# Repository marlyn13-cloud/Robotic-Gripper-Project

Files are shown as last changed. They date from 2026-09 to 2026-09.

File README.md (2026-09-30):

# Robotic-Gripper-Project

**Course:** CSIT431/CSIT531 — Introduction to Robotics

---

## Overview

Build a **Python GUI** (CustomTkinter) that controls a **3D-printed gripper** via an **Arduino Mega2560** over USB serial. A webcam feed uses **MediaPipe** to detect hand gestures, which open/close the gripper's **9g servo** in real time. The gripper must pick up **20 objects** of different shapes in a timed competition.

---

### Task
Use hand gesture recognition to control the gripper to **grasp objects from one box** and **deliver them to another box 30 cm away**.

### Rules
1. **20 objects** with different shapes, each labeled with a score
2. Distance between boxes: **30 cm**
3. **3 trials per object** — first-try success loses remaining trials for that object
4. Gripper must be controlled by **hand gesture recognition only**
5. **10 seconds per trial** — stop and start next trial if time runs out
6. Object falls INTO target box from gripper during delivery = **no points**
7. Object falls OUTSIDE target box = **get points but -1 deduction**
8. Gripper loses control = **-2 points per loss (max -8 deducted)**
9. Judges record scores on a performance sheet

---

## Part 1: 3D Design

### Selected Design
- **RobotGeek 9G Servo Gripper** — [Thingiverse thing:2083312](https://www.thingiverse.com/thing:2083312)
- Modify using **Tinkercad**, **Fusion 360**, or **Python (trimesh)**

### Design Requirements
| Parameter | Value |
|---|---|
| Hole size | 2.8 mm |
| Screw length compatibility | 18–24 mm |
| Servo attachment screws | No changes needed (keep as-is) |

### Bill of Materials (33 parts to print)

| # | Part | Qty | Notes |
|---|---|---|---|
| 1 | `BottomPlate.stl` | 1 | Base frame plate |
| 2 | `TopPlate.stl` | 1 | Top frame plate |
| 3 | `BackPlate.stl` | 1 | Rear structural support |
| 4 | `BackPlateSpacer.stl` | 1 | Rear spacer |
| 5 | `Gear.stl` | 1 | Central gear (servo-driven, hidden between plates) |
| 6 | `LeftFinger.stl` | **2** | Left gripper arms (stacked, has integrated gear teeth) |
| 7 | `RightFinger.stl` | **2** | Right gripper arms (stacked, has integrated gear teeth) |
| 8 | `FingerTip.stl` | **2** | Grip contact tips |
| 9 | `FingerTip-Plate.stl` | **4** | Tip mounting plates |
| 10 | `9GSpacer.stl` | 1 | Servo mount spacer |
| 11 | `9GSpacer-3mm.stl` | 1 | 3mm servo spacer variant |
| 12 | `3mmSpacer.stl` | **8** | General spacers (between plates) |
| 13 | `15mmStandoff.stl` | **8** | Standoffs (plate separation) |
| — | `Fitec-9g.stl` | — | Reference only — do NOT print |
| — | `GripperASM.stl` | — | Assembly reference — do NOT print |

### Hole Modifications (done via Python/trimesh)
- 7 parts modified: BottomPlate, TopPlate, LeftFinger, RightFinger, FingerTip-Plate, 3mmSpacer, 15mmStandoff
- All ~3.0 mm screw holes → **2.8 mm**
- Servo mount holes (2.0 mm) left unchanged

---

## Part 2: Hardware Setup

### System Diagram
```
  ┌──────────┐    USB     ┌──────────────┐   3 wires   ┌──────────┐
  │ COMPUTER │ ─────────> │   ARDUINO    │ ──────────> │ GRIPPER  │
  │ (Python  │   Serial   │  MEGA 2560   │  Red=5V     │ (9g Servo│
  │  GUI)    │            │              │  Brown=GND  │  inside) │
  └──────────┘            └──────────────┘  Yellow=A2  └──────────┘
       │
     Webcam
   (MediaPipe)
```

### Board
- **Arduino Mega2560** (provided by instructor)

### Servo Wiring
| Wire Color | Connect To |
|---|---|
| Red | 5V |
| Dark/Brown | Ground |
| Yellow/Signal | Pin **A2** (default in provided Arduino code) |

### Arduino Code
- Provided via Canvas — **no changes needed**
- Upload using Arduino IDE
- Install **Servo library**: [arduino.cc/libraries/servo](https://www.arduino.cc/reference/en/libraries/servo/)
- Serial port:
  - **Windows:** `COMx`
  - **macOS:** `/dev/cu.usbmodemXXXX`
- Python code supports **auto port detection**

---

## Part 3: Python Development

### Environment
- **Python version:** 3.11 or 3.12 (64-bit) — compatible with MediaPipe (supports 3.9–3.12)
- **IDE:** VSCode with **Python Extension Pack** (optional but recommended)

### Dependencies (install via pip)
```
pip install pyserial customtkinter mediapipe opencv-contrib-python
```

| Package | Purpose |
|---|---|
| `pyserial` | Serial communication with Arduino Mega2560 |
| `customtkinter` | Modern Python GUI framework |
| `mediapipe` | Hand landmark / gesture detection |
| `opencv-contrib-python` | Camera input & image processing |

### Architecture
1. **GUI (CustomTkinter)** — Main window with camera feed, controls, and status
2. **Hand Tracking (MediaPipe + OpenCV)** — Detect hand landmarks from webcam
3. **Gesture Interpretation** — Map hand open/close to gripper open/close commands
4. **Serial Communication (pyserial)** — Send servo angle commands to Arduino over USB
5. **Auto Port Detection** — Automatically find the connected Arduino serial port

### Workflow
1. Connect Arduino Mega2560 via USB (servo already wired)
2. Run the Python GUI (`python xxx.py`)
3. Select Python 3.x interpreter in VSCode if needed
4. Serial port is auto-detected (or manually set in code)
5. Webcam opens → MediaPipe tracks hand → gestures control gripper

---

## Part 4: Test Objects (20 in competition)

Items in the project box — each labeled with a score. Must grasp from one box and deliver to another (30 cm apart).

| # | Object | Notes | Difficulty |
|---|---|---|---|
| 1 | 9g Servo motor (blue) | Small, rigid, rectangular | Easy |
| 2 | Yellow servo/motor component | Small, irregular shape | Easy |
| 3 | 3D printed robotic arm/hand | Gray, multi-part, medium size | Medium |
| 4 | Long screw/bolt | Thin, cylindrical | Hard |
| 5 | Plastic fork | Lightweight, flat handle | Medium |
| 6 | Green lid/cap | Round, flat | Medium |
| 7 | Red container/jar | Cylindrical, medium | Easy |
| 8 | Yellow wheel/gear piece | Round with spokes | Medium |
| 9 | 3D printed head | Gray, large, heaviest item | Hard |
| 10 | Orange craft knife | Thin, elongated | Medium |
| 11 | Blue donut/ring | Round, hollow center | Medium |
| 12 | Tube (glue or similar) | Cylindrical, small | Easy |
| 13 | Small connectors & wires | Various tiny parts | Hard |

*Competition will have 20 objects total — these are samples.*

---

## Resources

### Servo Control
- [Arduino Servo Library](https://www.arduino.cc/reference/en/libraries/servo/)
- [Servo Motor with Arduino](https://makersportal.com/blog/2020/3/14/arduino-servo-motor-control)
- [Python + Arduino Servo](https://github.com/jumejume1/python-arduino-basic/tree/main/servo-control)

### Arduino Reference
- [Arrays](https://www.arduino.cc/reference/en/language/variables/data-types/array/)
- [If Statement](https://www.arduino.cc/reference/en/language/structure/control-structure/if/)
- [For Loops](https://www.arduino.cc/reference/en/language/structure/control-structure/for/)
- [While Loops](https://www.arduino.cc/reference/en/language/structure/control-structure/while/)

### Other Gripper Designs for Reference
- [EEZYbotARM](https://www.thingiverse.com/thing:2195839)
- [Simple 9g Servo Gripper](https://www.thingiverse.com/thing:2302957)
- [Rack & Pinion Gripper](https://www.thingiverse.com/thing:2661755)
- [3-Finger Chess Robot Gripper](https://www.thingiverse.com/thing:1322867)
- [Parametric Robot Claw](https://www.thingiverse.com/thing:27468)
----------
Demo Video Link

https://drive.google.com/file/d/11LuLujdieBRYz85RrpzKWeHXCLVEo9Aj/view?usp=sharing

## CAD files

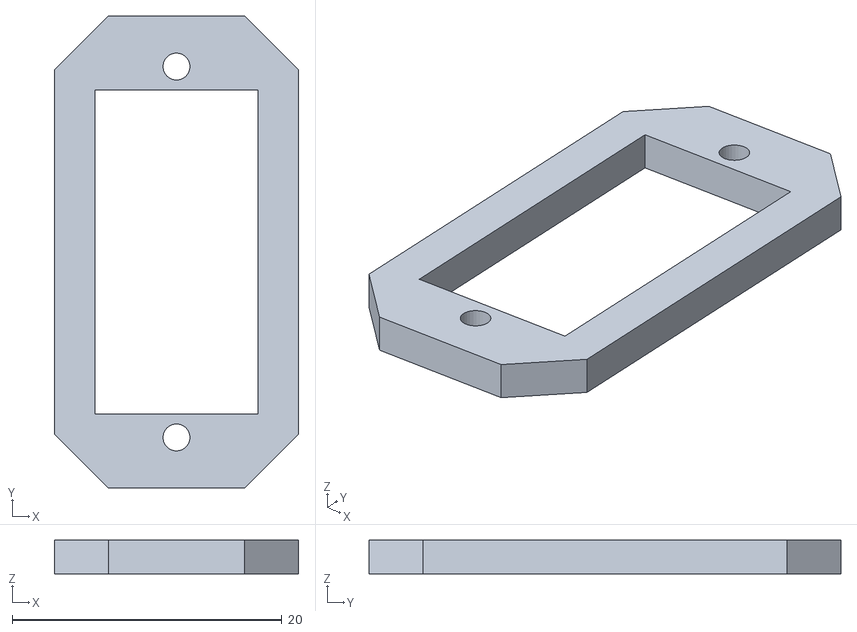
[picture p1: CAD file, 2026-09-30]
STL-Final/9GSpacer-3mm.stl
18.1 x 35.0 x 2.50

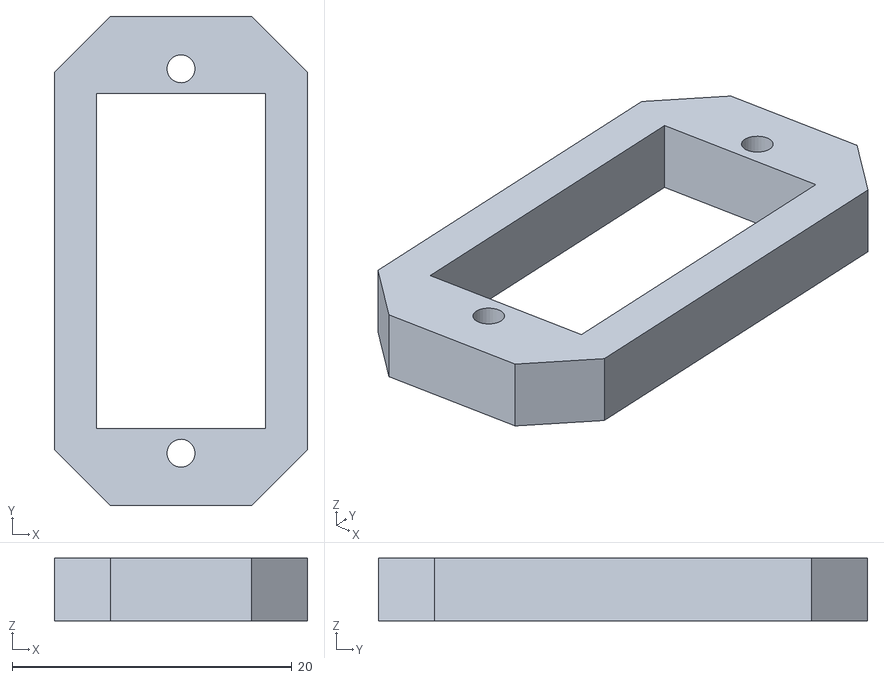
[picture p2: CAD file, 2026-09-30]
STL-Final/9GSpacer.stl
18.1 x 35.0 x 4.50

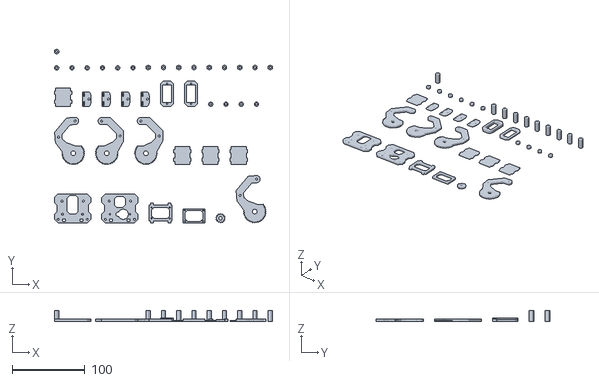
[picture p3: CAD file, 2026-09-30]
STL-Final/ALL_33_PARTS.stl
300.0 x 239.3 x 15.0

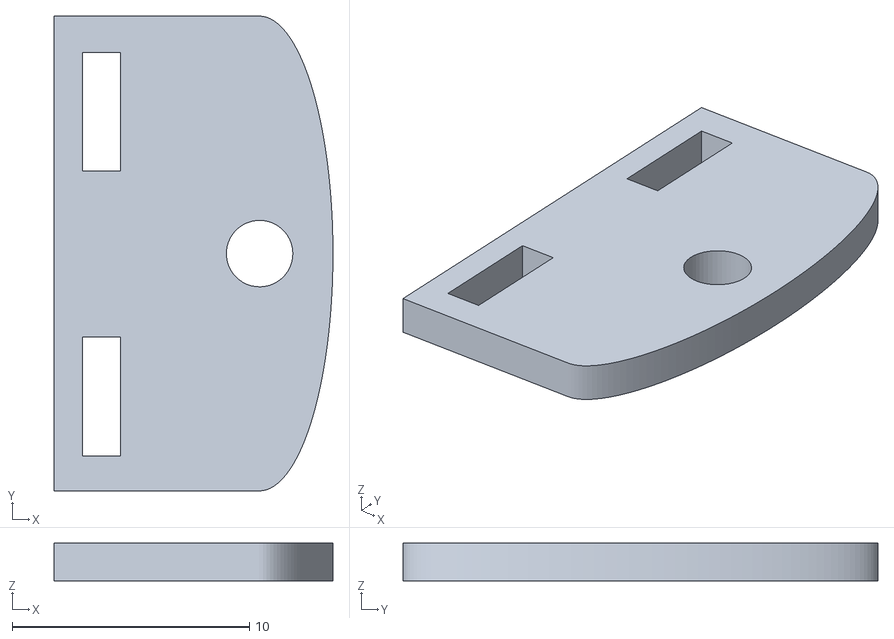
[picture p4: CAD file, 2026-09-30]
STL-Final/FingerTip-Plate.stl
11.8 x 20.0 x 1.60

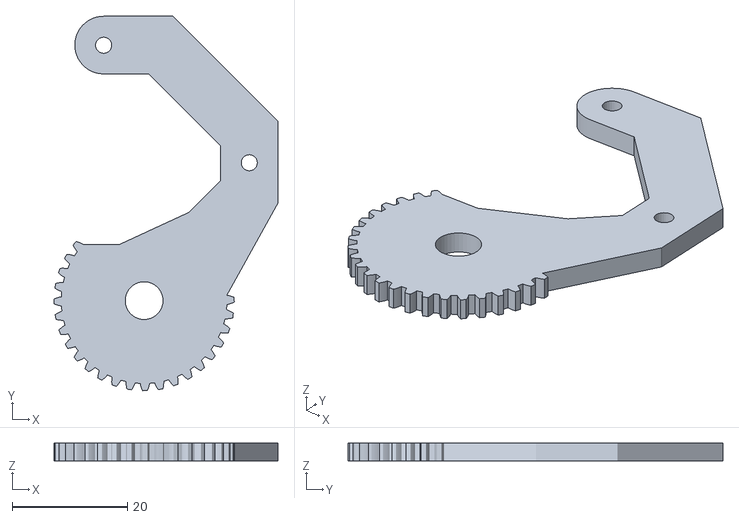
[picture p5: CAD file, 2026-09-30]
STL-Final/RightFinger.stl
38.8 x 64.9 x 3.10

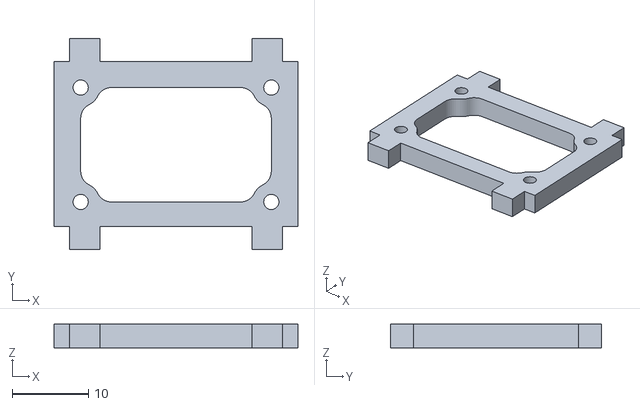
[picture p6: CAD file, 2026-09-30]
STL-Final/BackPlate.stl
32.0 x 27.7 x 3.10

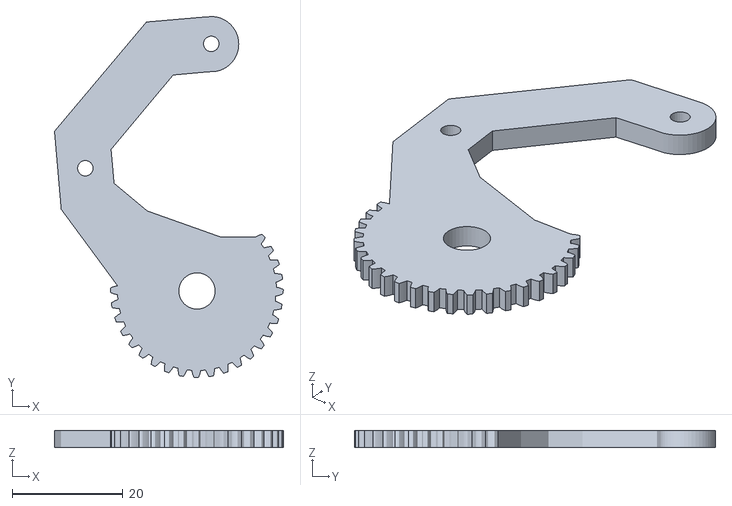
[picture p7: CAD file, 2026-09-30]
STL-Final/LeftFinger.stl
41.4 x 65.2 x 3.10

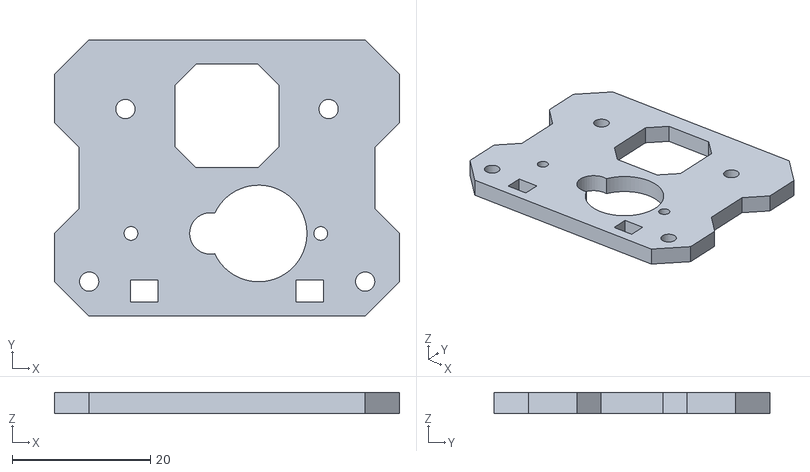
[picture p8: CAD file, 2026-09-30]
STL-Final/TopPlate.stl
50.0 x 40.0 x 3.10

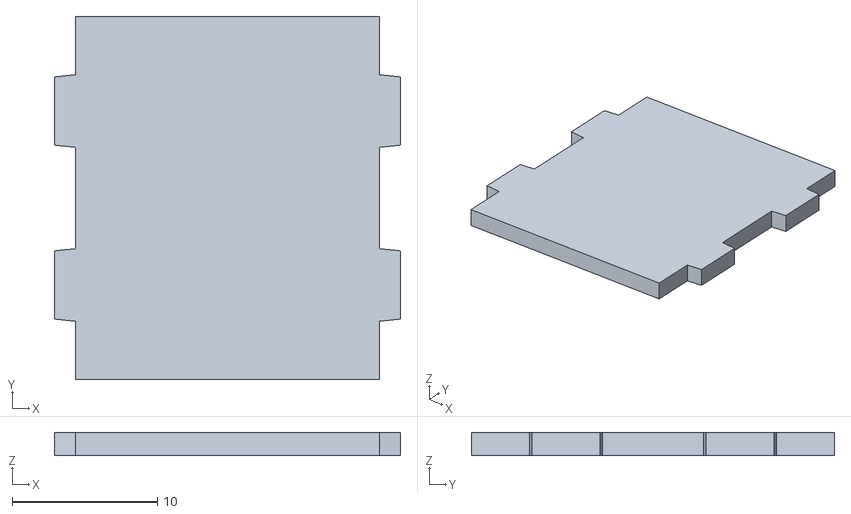
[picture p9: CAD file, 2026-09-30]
STL-Final/FingerTip.stl
23.8 x 25.0 x 1.60

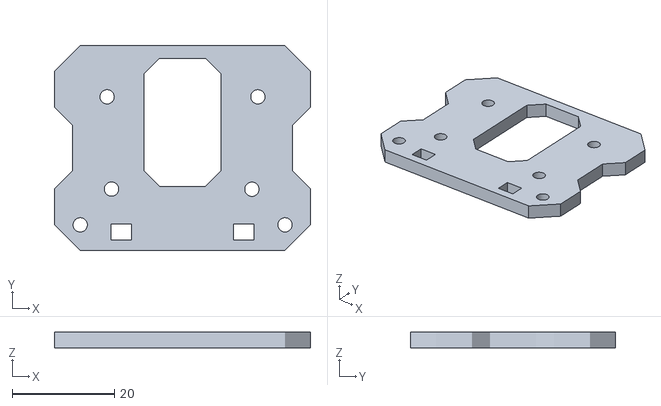
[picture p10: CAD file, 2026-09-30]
STL-Final/BottomPlate.stl
50.0 x 40.0 x 3.10

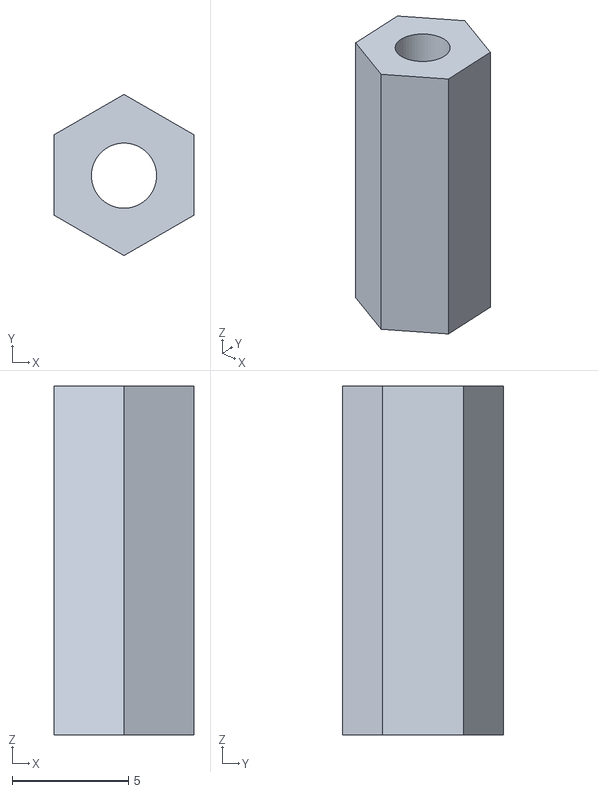
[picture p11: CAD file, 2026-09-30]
STL-Final/15mmStandoff.stl
6.00 x 6.93 x 15.0

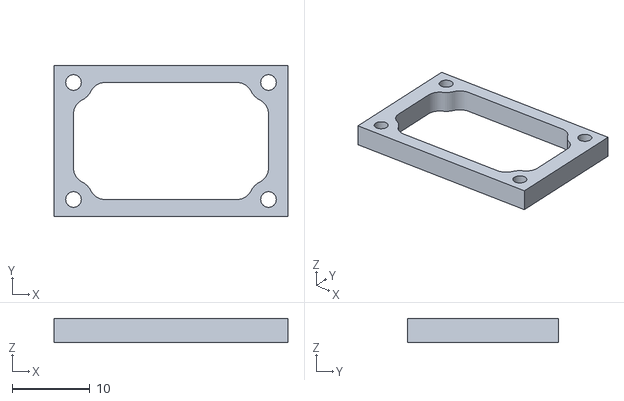
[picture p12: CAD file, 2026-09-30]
STL-Final/BackPlateSpacer.stl
30.0 x 19.3 x 3.10

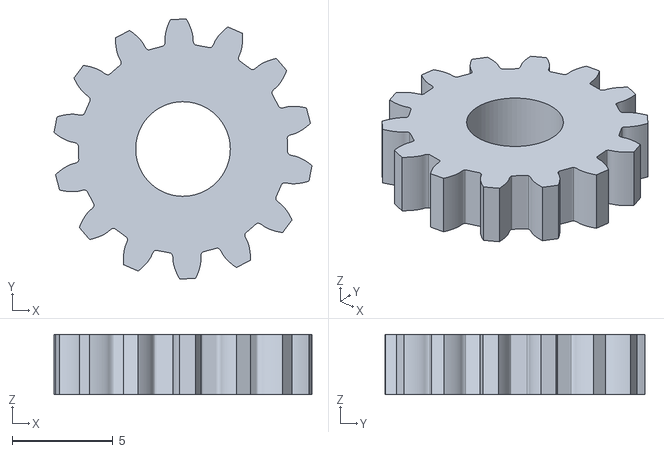
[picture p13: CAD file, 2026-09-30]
STL-Final/Gear.stl
12.8 x 12.9 x 3.00

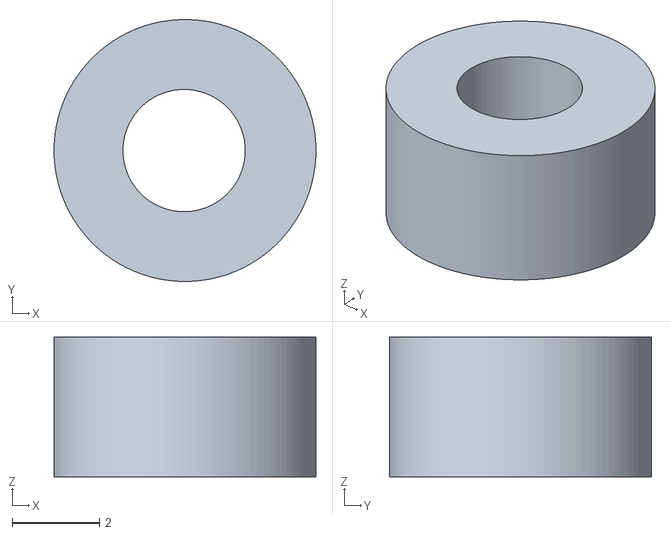
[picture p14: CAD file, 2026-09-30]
STL-Final/3mmSpacer.stl
6.00 x 6.00 x 3.20

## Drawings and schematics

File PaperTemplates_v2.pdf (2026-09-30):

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

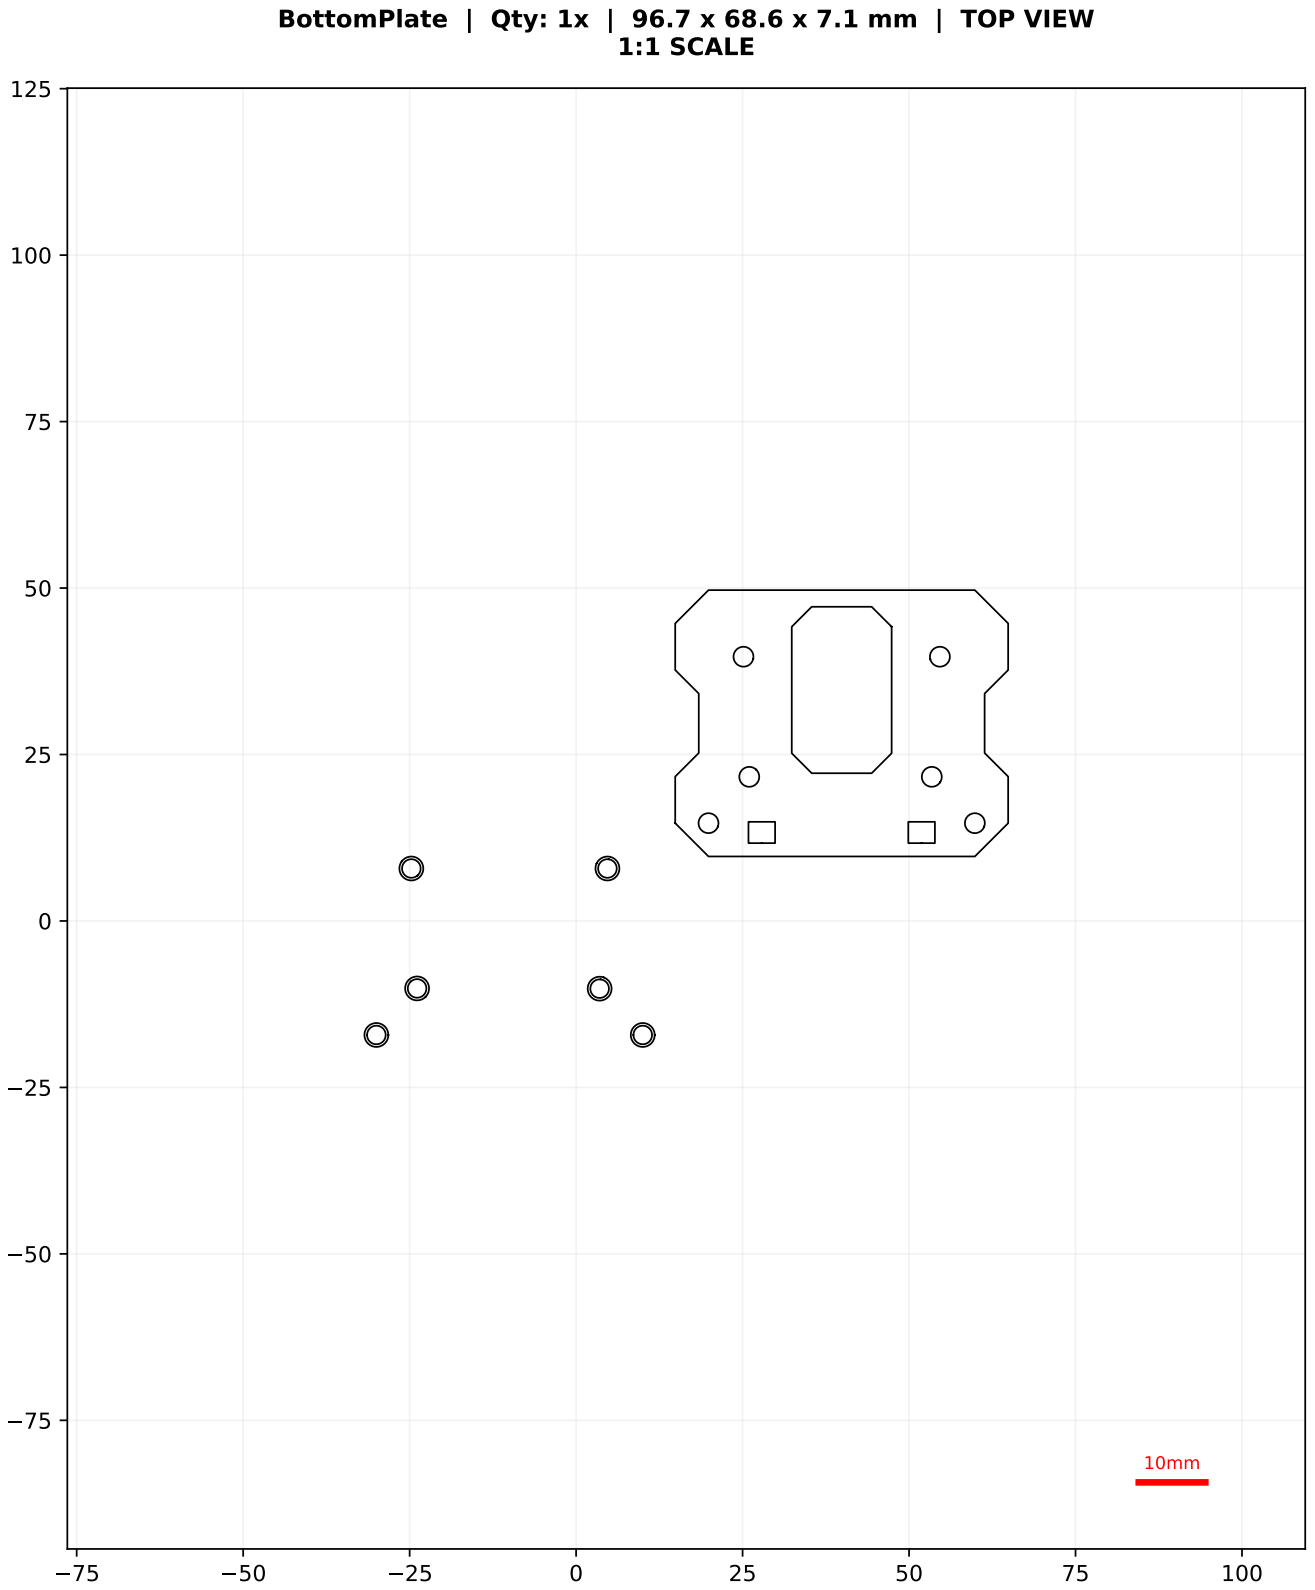
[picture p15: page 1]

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

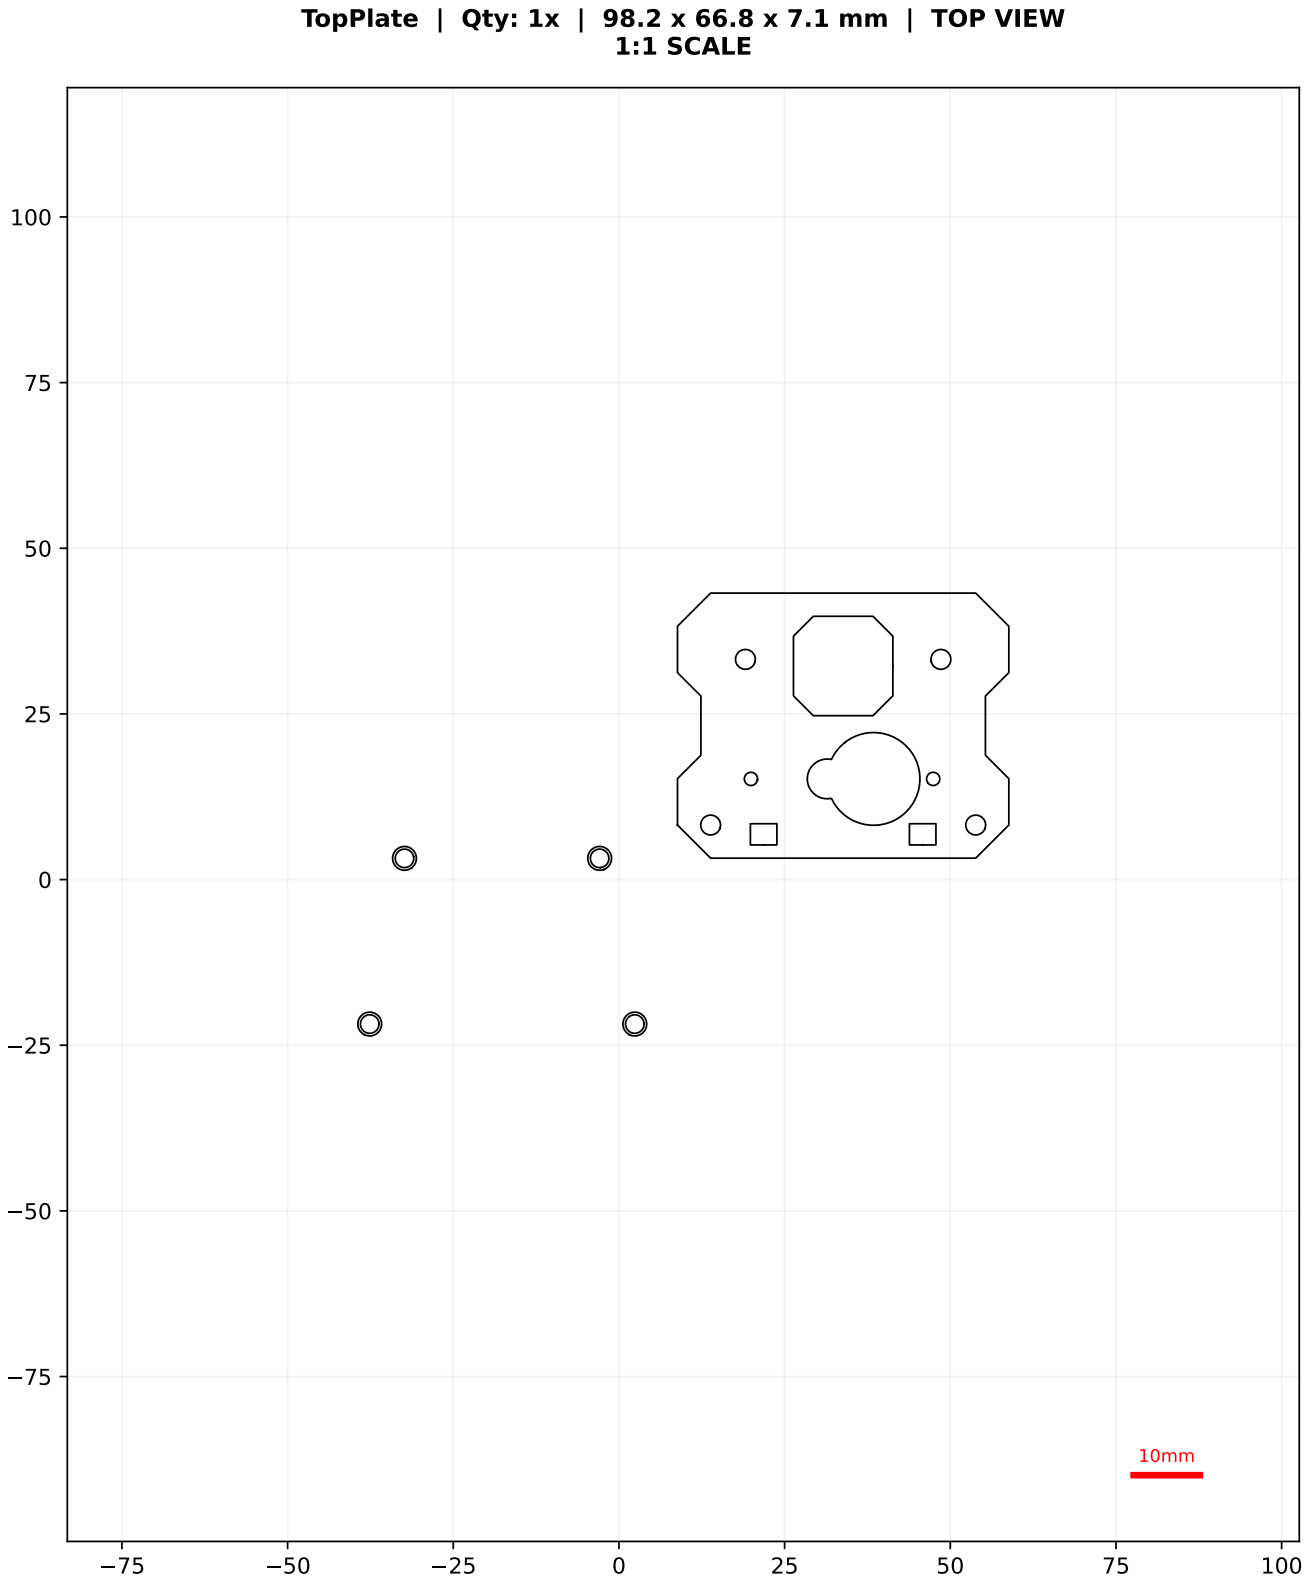
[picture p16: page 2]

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

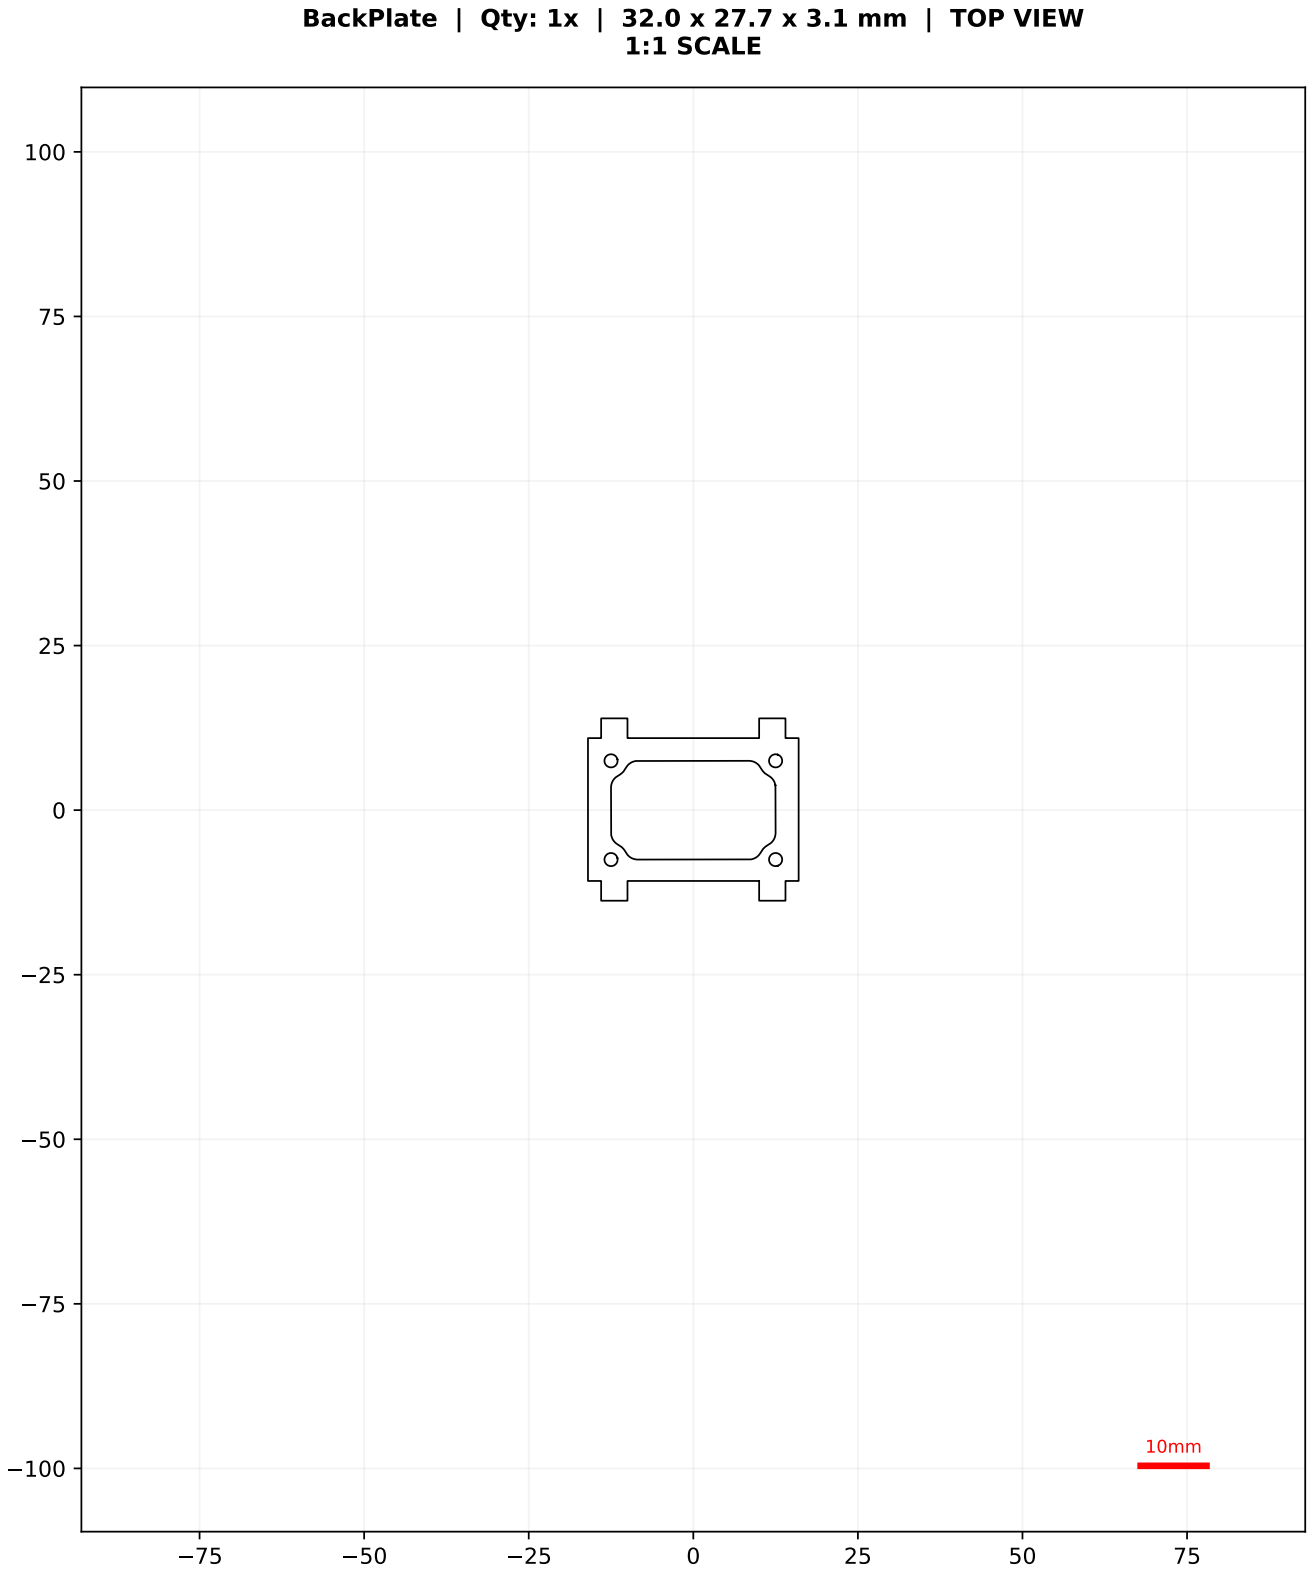
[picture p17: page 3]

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

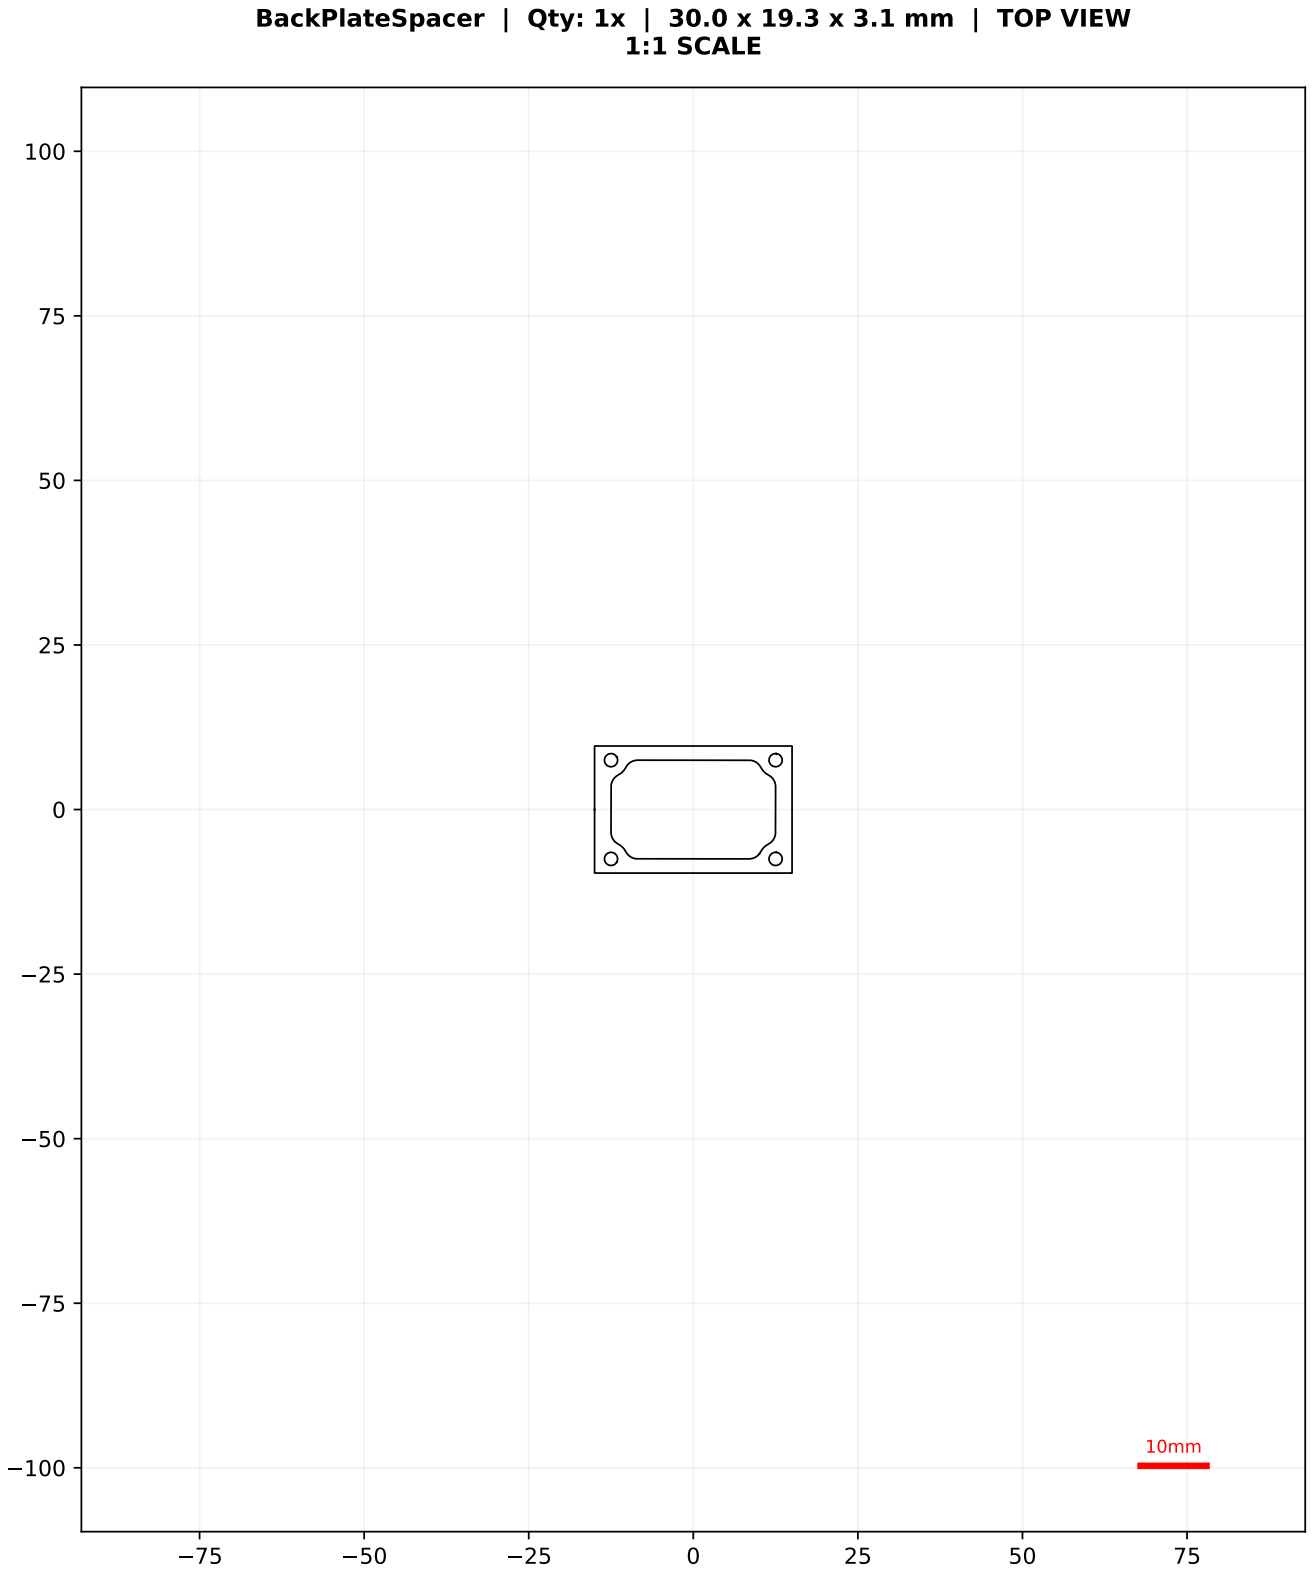
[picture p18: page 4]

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

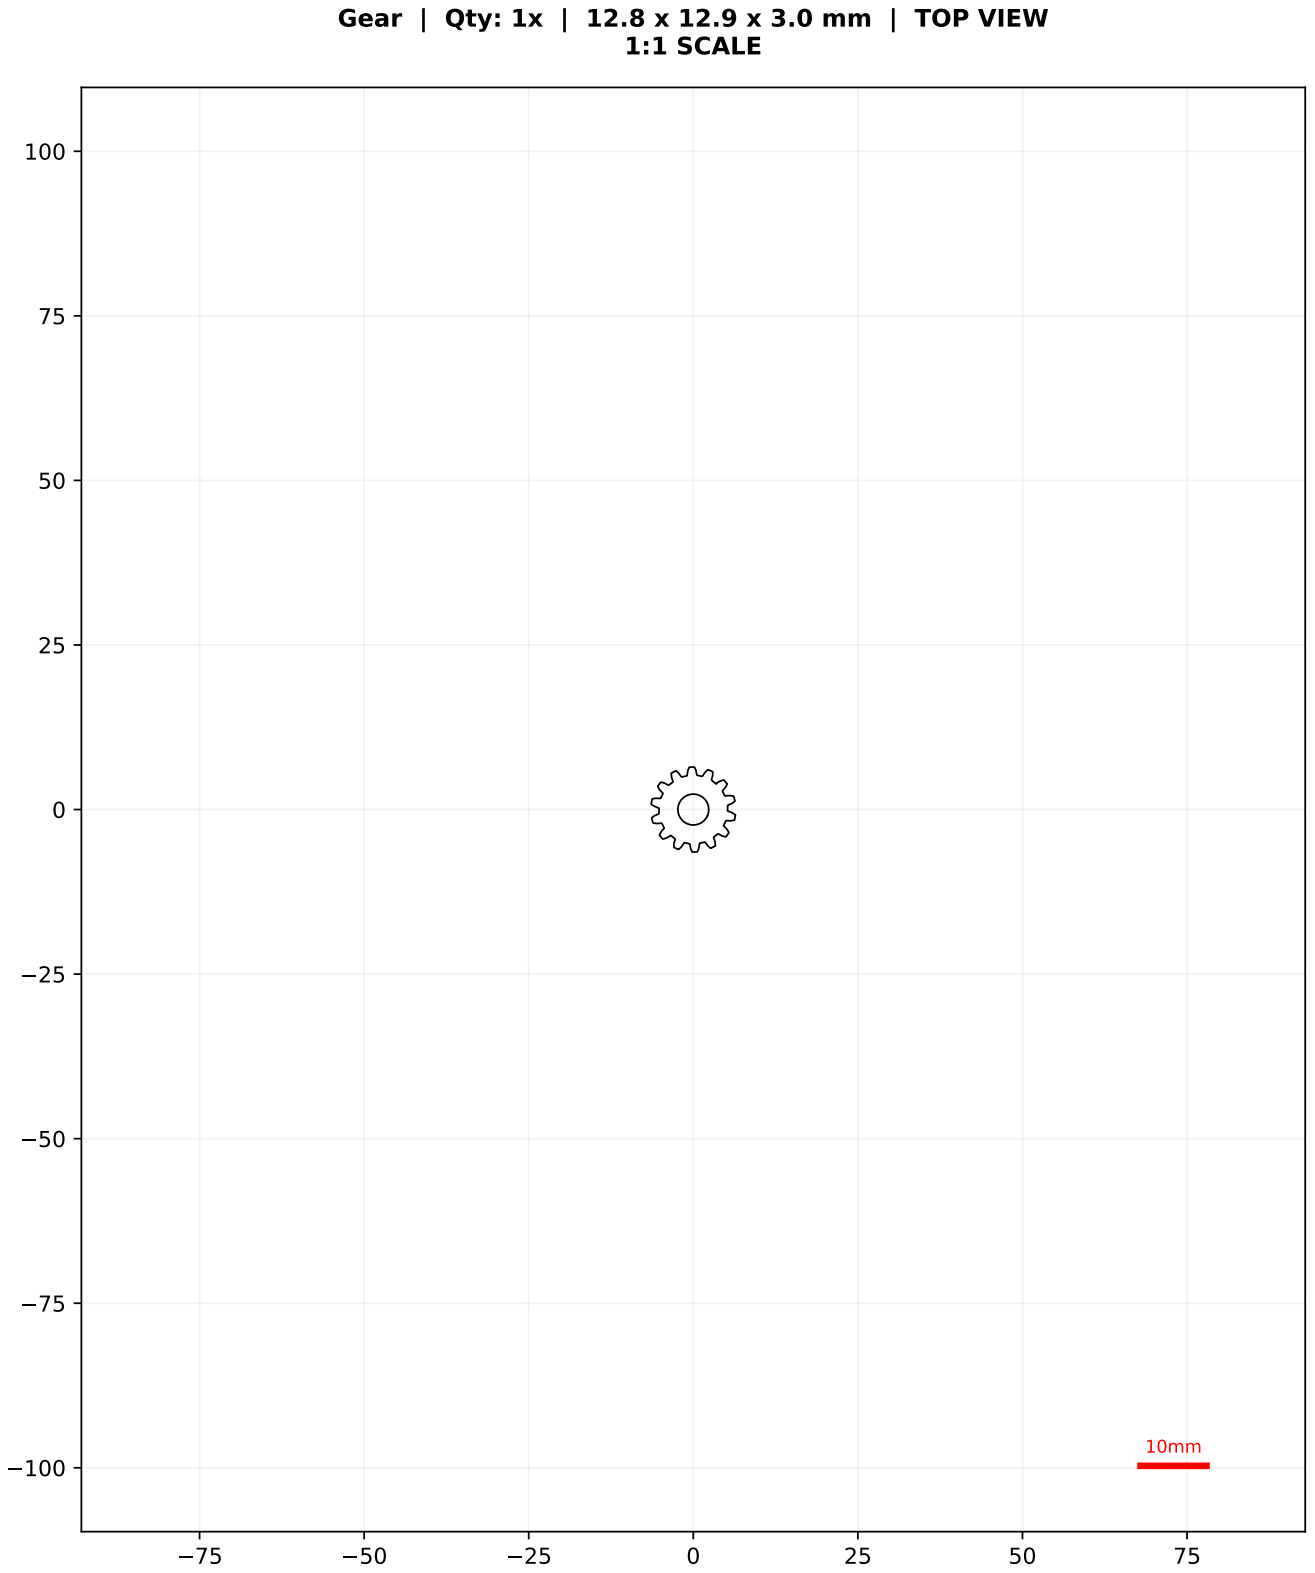
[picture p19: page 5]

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

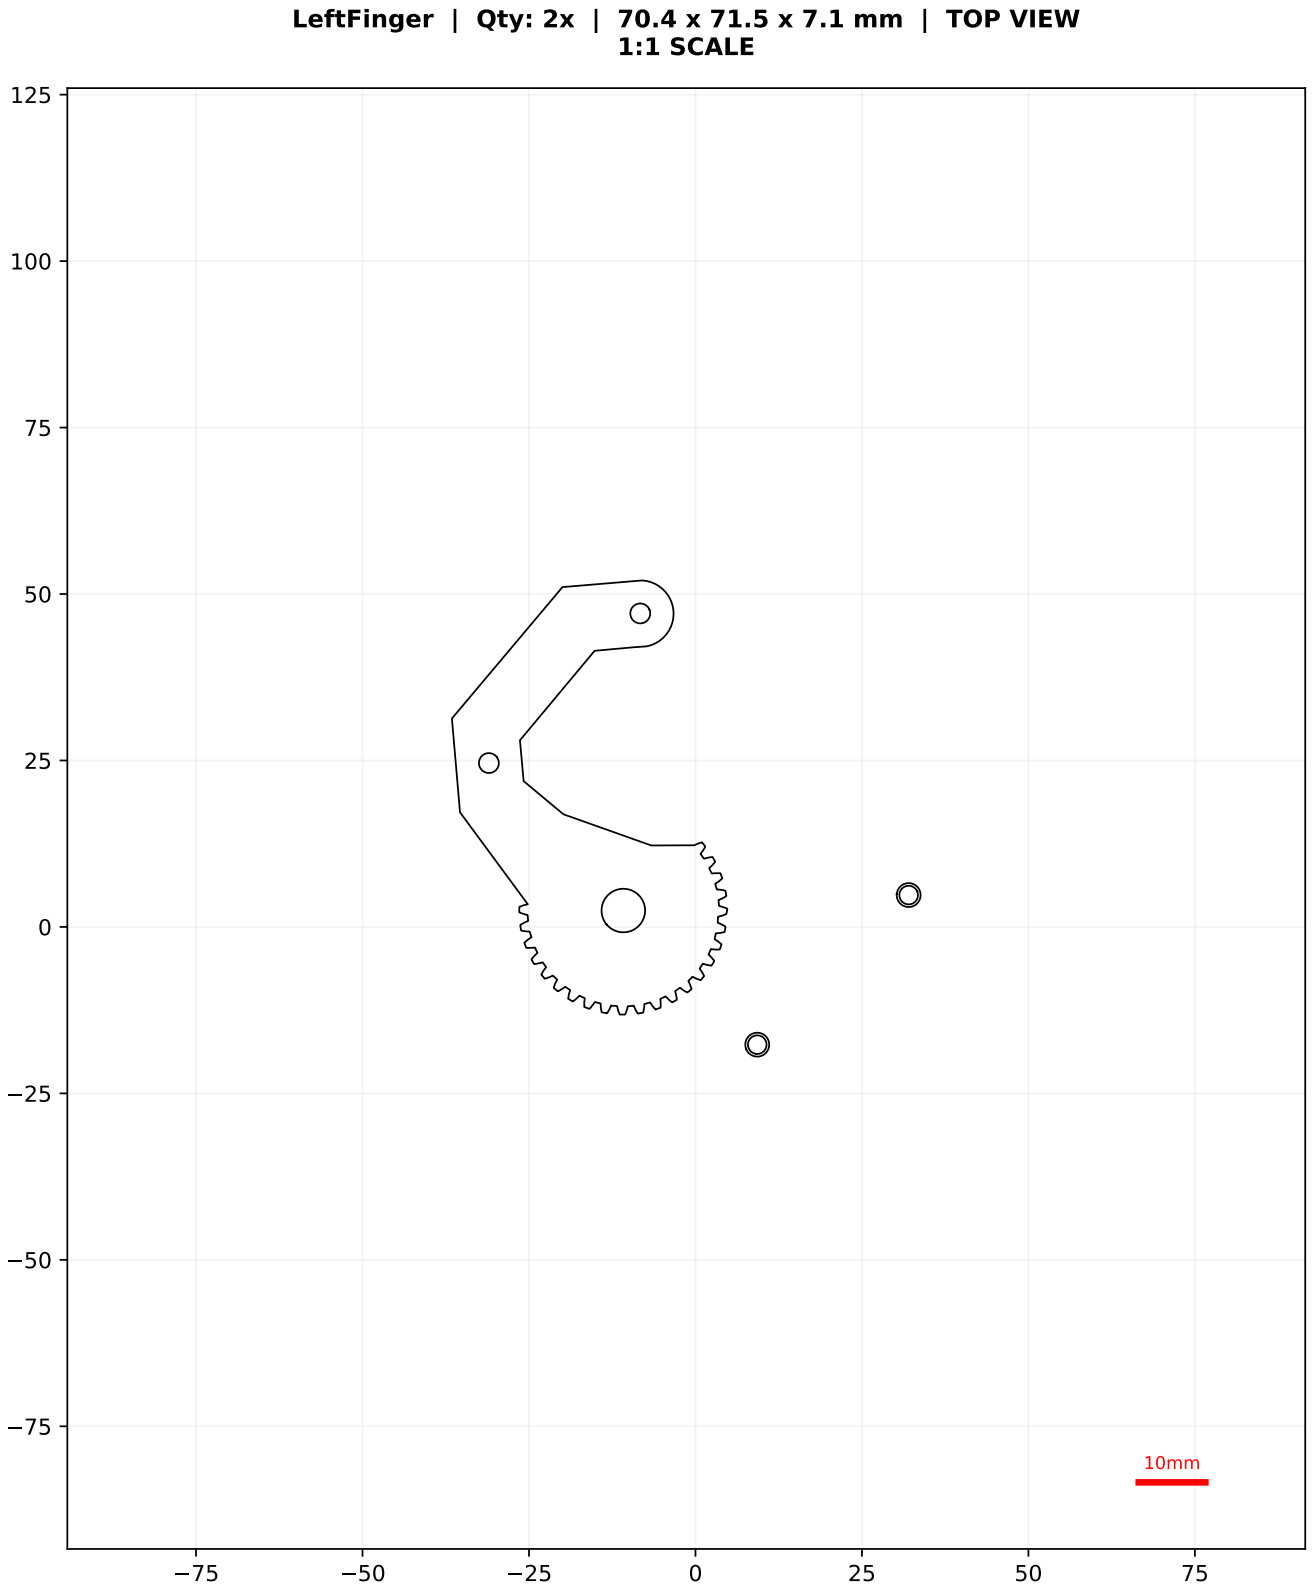
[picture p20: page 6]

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

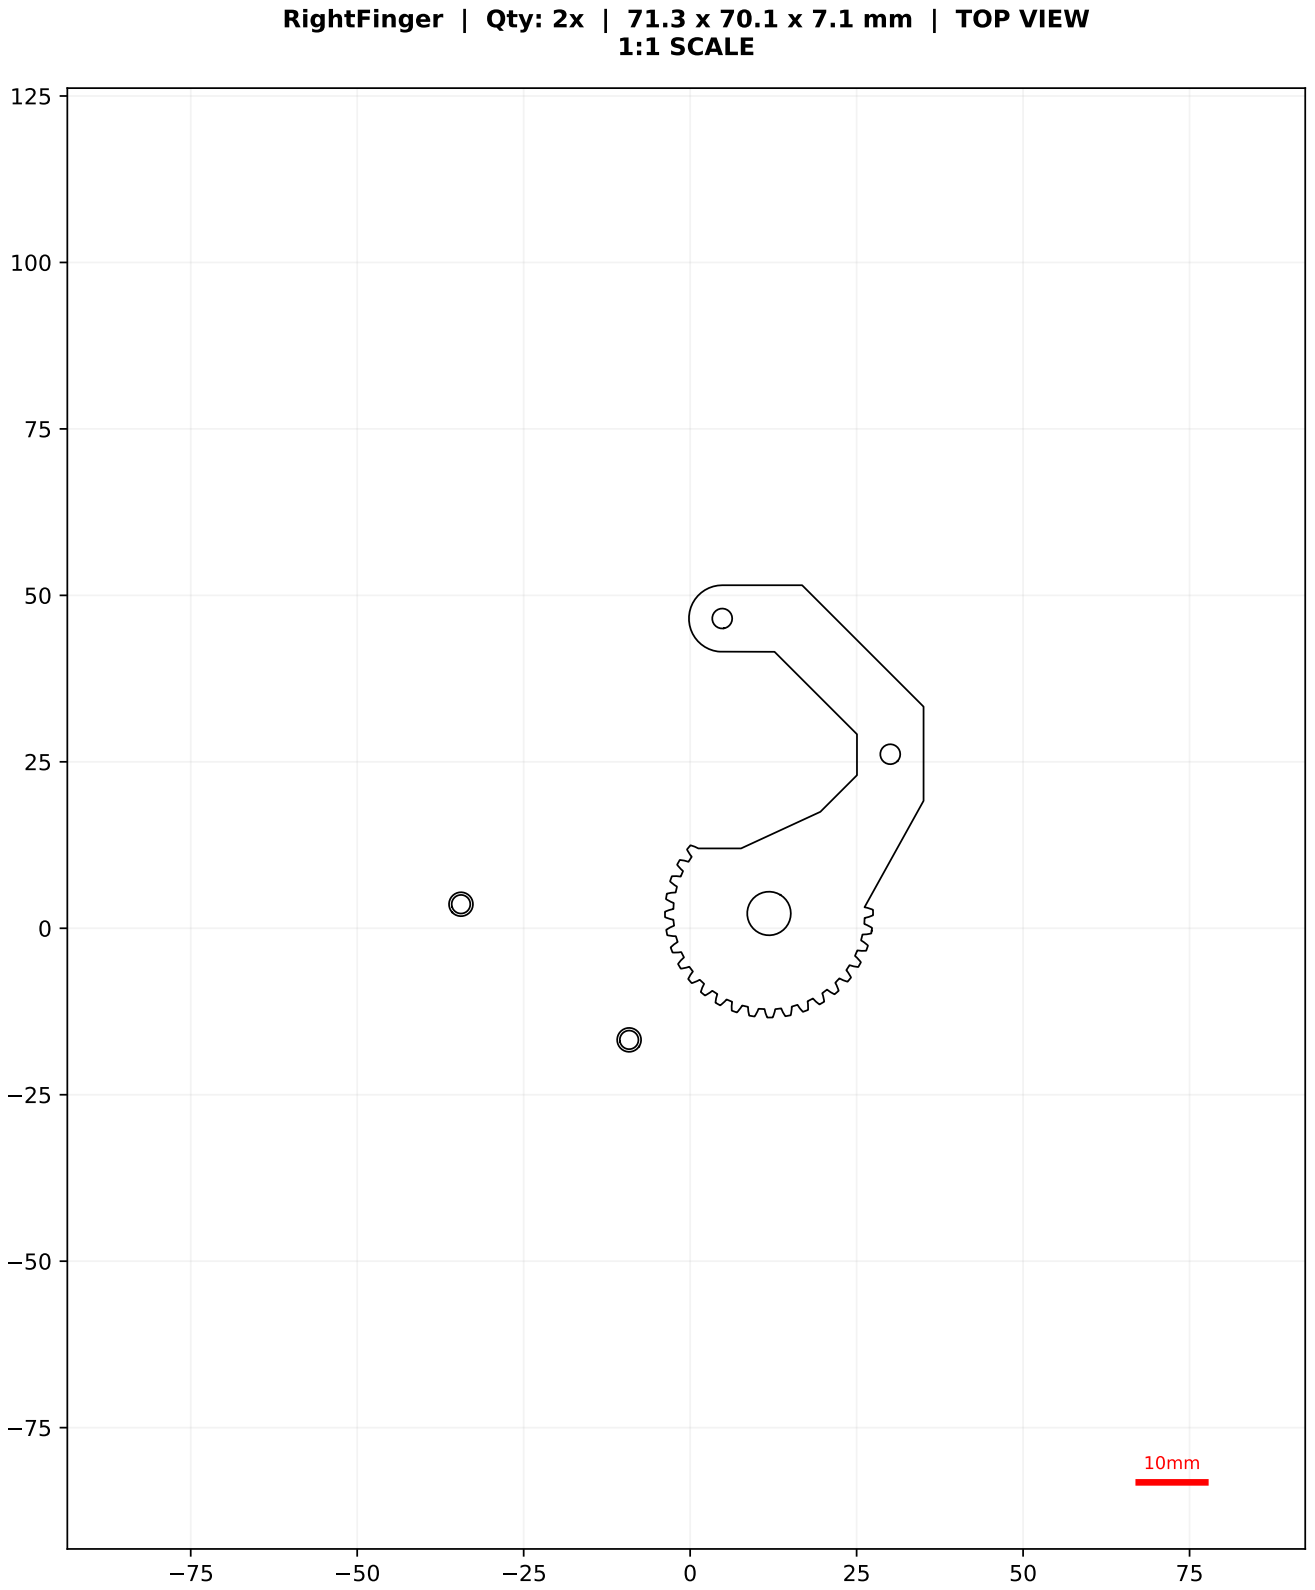
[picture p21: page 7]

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

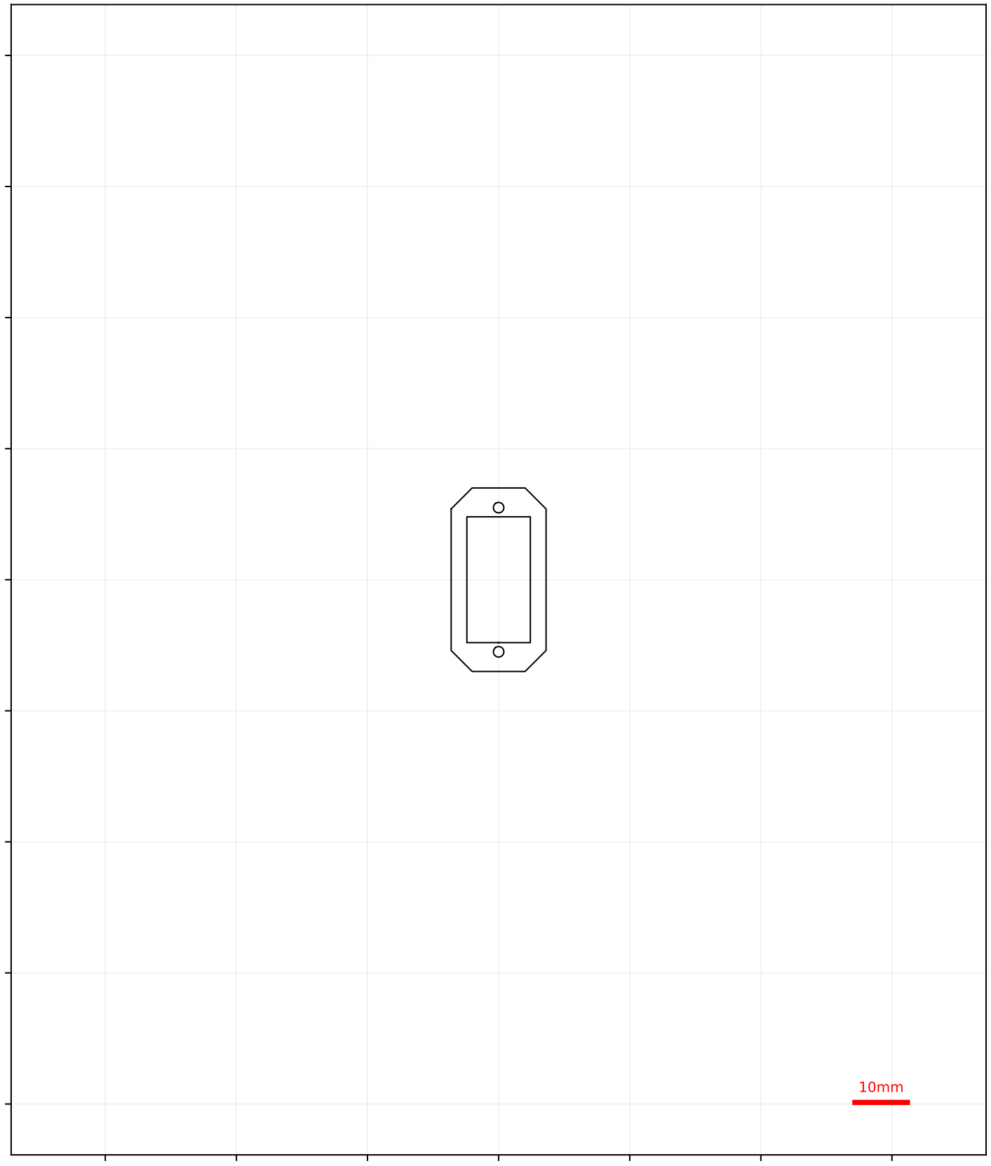
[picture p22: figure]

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

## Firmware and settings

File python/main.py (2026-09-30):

"""
Robot Gripper — Hand Gesture Control
=====================================
Controls a 3D-printed gripper via Arduino Mega2560 using
hand gesture recognition (MediaPipe + OpenCV).

Usage:
    python main.py

Requirements:
    pip install pyserial customtkinter mediapipe opencv-contrib-python pillow
"""

from serial_controller import SerialController
from hand_tracker import HandTracker
from gui import GripperGUI


def main():
    serial = SerialController(baud_rate=9600)
    tracker = HandTracker(smoothing_window=5)
    app = GripperGUI(serial, tracker)
    app.start()


if __name__ == "__main__":
    main()

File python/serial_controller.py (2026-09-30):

import serial
import serial.tools.list_ports
import threading
import time


class SerialController:
    def __init__(self, baud_rate=9600):
        self.baud_rate = baud_rate
        self.connection = None
        self.connected = False
        self.port_name = None
        self._lock = threading.Lock()
        self._last_send_time = 0
        self._min_interval = 0.05  # 50ms between commands

    def auto_detect_port(self):
        """Find the Arduino Mega serial port automatically."""
        ports = serial.tools.list_ports.comports()
        for port in ports:
            desc = (port.description + " " + port.manufacturer).lower() if port.manufacturer else port.description.lower()
            if any(keyword in desc for keyword in ["arduino", "mega", "usb", "usbmodem", "usbserial", "ch340", "cp210"]):
                return port.device
        # Fallback: return first /dev/cu.usbmodem or COM port
        for port in ports:
            if "usbmodem" in port.device or "usbserial" in port.device or "COM" in port.device:
                return port.device
        return None

    def list_ports(self):
        """Return list of available serial ports."""
        return [(p.device, p.description) for p in serial.tools.list_ports.comports()]

    def connect(self, port=None):
        """Connect to Arduino. Auto-detects port if not specified."""
        if self.connected:
            self.disconnect()

        if port is None:
            port = self.auto_detect_port()
        if port is None:
            raise ConnectionError("No Arduino found. Check USB cable.")

        try:
            self.connection = serial.Serial(port, self.baud_rate, timeout=1)
            time.sleep(2)  # Arduino resets on serial connect
            self.port_name = port
            self.connected = True
            # Read the READY message
            if self.connection.in_waiting:
                self.connection.readline()
            return port
        except serial.SerialException as e:
            self.connected = False
            raise ConnectionError(f"Could not connect to {port}: {e}")

    def disconnect(self):
        """Close the serial connection."""
        with self._lock:
            if self.connection and self.connection.is_open:
                self.connection.close()
            self.connected = False
            self.port_name = None

    def send_angle(self, angle):
        """Send a servo angle (0-180) to Arduino. Rate-limited to 50ms."""
        if not self.connected:
            return False

        angle = max(0, min(180, int(angle)))

        # TODO (from Arduino repo idea): add self._prev_angle and skip write
        # when angle == self._prev_angle, like their prev_finger_count pattern.
        # Currently we already rate-limit at 50ms, but dedup would also avoid
        # sending identical values when the hand is steady.

        now = time.time()
        if now - self._last_send_time < self._min_interval:
            return True  # Skip, too fast

        with self._lock:
            try:
                self.connection.write(f"{angle}\n".encode())
                self._last_send_time = now
                return True
            except serial.SerialException:
                self.connected = False
                return False

    def read_response(self):
        """Read a response line from Arduino (non-blocking)."""
        if not self.connected:
            return None
        with self._lock:
            try:
                if self.connection.in_waiting:
                    return self.connection.readline().decode().strip()
            except serial.SerialException:
                self.connected = False
        return None

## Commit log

2026-09-30 Add final STL prints for robotic gripper
2026-09-30 Add gripper control with servo in Arduino sketch
2026-09-30 Add servo control for gripper with auto demo
2026-09-30 Add Gripper GUI with camera and gesture control
    Implement Gripper GUI for hand gesture control using OpenCV and CustomTkinter.
2026-09-30 Add main.py for hand gesture control of robot gripper
    Initial implementation of a hand gesture control system for a robot gripper using MediaPipe and OpenCV.
2026-09-30 Implement SerialController for Arduino communication
    This class handles serial communication with an Arduino, including auto-detection of the port, connection management, and sending commands.
2026-09-30 Add servo test script for Arduino control
    This script connects to an Arduino and sweeps a servo between specified angles.
2026-09-30 Enhance README with project details and instructions
    Added detailed project overview, task description, rules, design requirements, hardware setup, Python development environment, and resources for the Robotic Gripper Project.
